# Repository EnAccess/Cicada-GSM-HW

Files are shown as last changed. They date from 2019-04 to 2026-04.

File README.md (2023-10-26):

<p align="center">
  <a href="https://github.com/EnAccess/Cicada-GSM-HW">
    Cicada GSM
  </a>
</p>
<p align="center">
    <em>IoT Communications Module for Energy Access. A quick way to get production ready, bi-directional communications for your IoT embedded device.</em>
</p>
<p align="center">
  
  
  <a href="https://github.com/EnAccess/Cicada-GSM-HW/blob/main/LICENSE" target="_blank">
    
  </a>
</p>

---

# Cicada HW - IoT Communications Module for Energy Access

This repository contains the hardware design of IOT embedded bi-directional communications device. through  2G, 3G, 4G modemsTech.

Checkout the examples in the firmware repository here <https://github.com/EnAccess/Cicada>

## Manufacturing files

If you are only interested in manufacturing the PCBs, you only need files in the /manufacturing/ directory. send them to your contract manufacturer of choice,Some examples of other turnkey PCBA manufacturers are:

| Manufacturers |
|---------------|
| JLCPCB |
| PCBCart |
| Bittele |

The /manufacturing/ directory contains the PCB Gerber/drill files, the BOM, and assembly instructions.

## Source files

If you'd like to take a look at the schematics and PCB layout, first, make sure you have a fresh version of KiCAD. It's a free and open source electronics design tool, and can be downloaded from <http://kicad.org>. Make sure you are not using an old version that some Linux distributions might be still shipping.

### File structure

The schematics and related files live under the /design/ directory:

| Directory | Content |
|---|---|
| /design/doc/datasheets/ | Datasheets for some of the components used. These files are not covered by this project's open source licence |
| /design/pdf | Schematics exported as PDF |
| /design/source/kicad/ | Kicad source files for the CICADA GSM hardwares inculding component lib files |
| /manufacturing/gerber/ |  these are set of files which gives information on different layers used in the project (copper layers, silk screen , court yard and other relevent files) |
| /manufacturing/stackup/ | Text file containing the details of the PCB material and stackup |
| /manufacturing/pick and place/ | Pick and place files describing component locations and orientations for PCB Assembly |
| /manufacturing/nc drill/ | NC Drill files describing type and specification of PCB drill holes (vias, through holes, mounting holes etc) |
| /manufacturing/BOM/ | BOM contains the imformation of all the components used for cicad. directely generated from Kicad using the bom genration script  |

## Standard KiCAD libraries

To make sure we are using the same version of standard KiCAD libraries, we've made a proxy repo that references the KiCAD github repositories, <https://github.com/EnAccess/kicad-libs>. Please clone it along side this repositories, and KiCAD should be able to pick up the schematics symbols / footprints from there:

`/Cicada-HW/` - This repo.

`/kicad-libs/` - Kicad libraries repo.

You might want to remove "global" kicad libraries from your settings to avoid possible version mismatches.

# A quick look at the schematics

The schematics are lagely based on the `SIM7600 Series_Hardware Design_V1.02` and `SIM800C_Hardware_Design_V1.05` documents from Simcom, both found in the documentation folder. Most design festures are shared between the 2G and 4G boards.

## Host interface

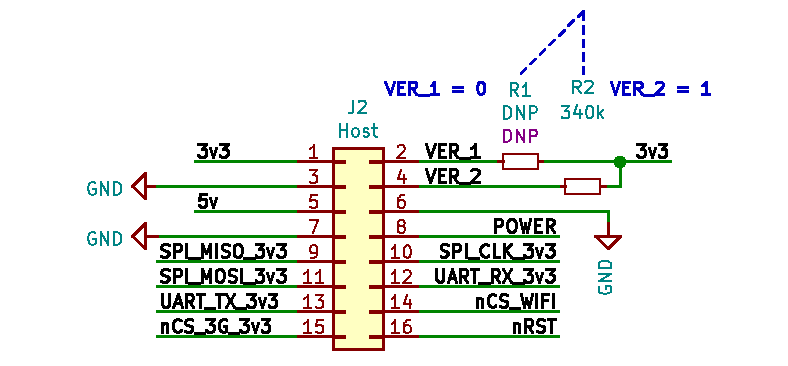
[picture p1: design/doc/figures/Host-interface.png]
Host interface


The host interface provides:

- 5V - power
- 3.3v - logic level VCC reference.
- VER_1 and VER_2 - version pins.
- UART TX and RX.
- SPI - only available on the 4G board as an option. Normally, UART can be used for communication.
- POWER enable pin - drive hogh to enable power.
- RESET pin - drive low to reset, drive at 1.8 - 3.3v during normal operation. Is not implemented on the 2G board, since the SIM800C chip does not have a RESET line.

## Version information

The host interface provides a way for the host to detect the presence of a Cicada board, and distinguish between different boards:

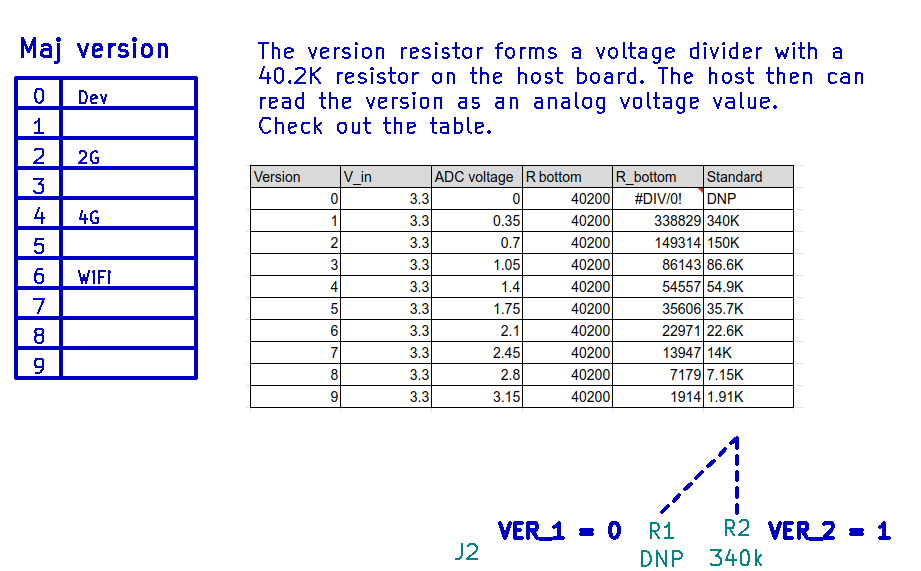
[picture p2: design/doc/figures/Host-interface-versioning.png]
Host interface versioning


## Sim card slot

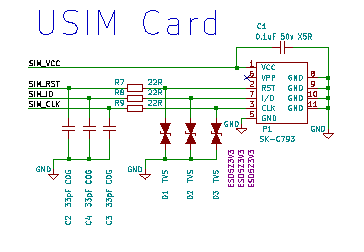
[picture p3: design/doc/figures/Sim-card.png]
Sim card


Same for Cicada 2G and Cicada 4G boards.

## Power

Both Cicada 2G and Cicada 4G use single-chip SMPS to convert 5v down to 4v required by both SIM7600 and SIM800C modules.

Both the modules use M3406-ADJ, which come with a internal over current protection (1.5A) and rated to 800mA operation. but the power supply circuit is design with the bulk output Capacitance which maintaines the voltage and pumps the shorter peak current requirment and the series resister at the power supply input reduce the stress on the hosts 5v regulator.

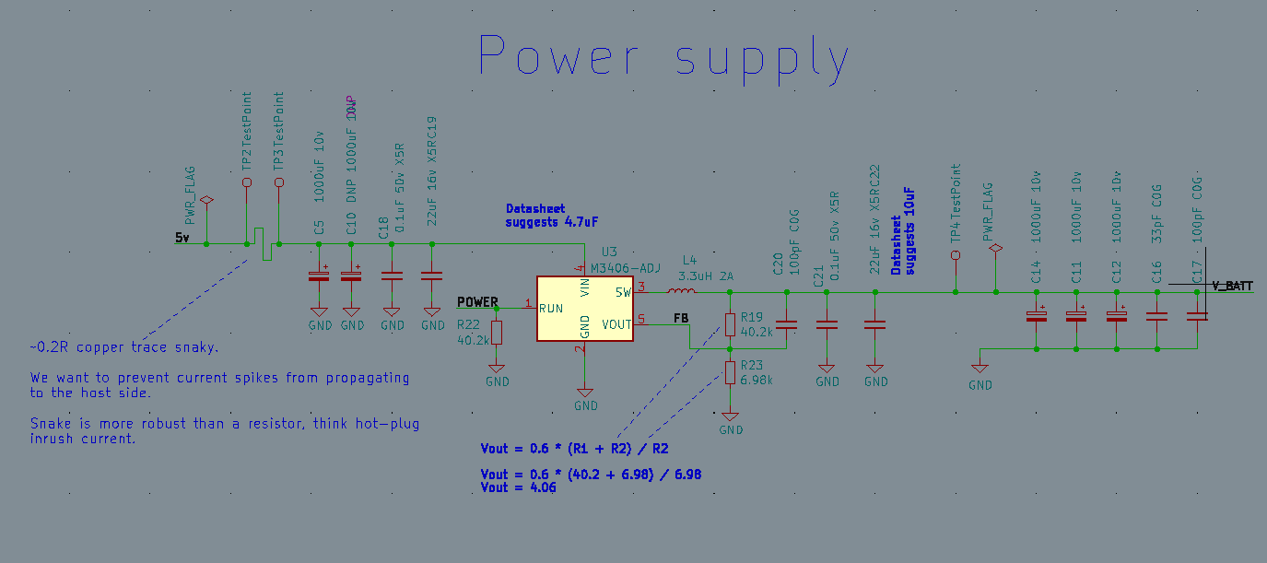
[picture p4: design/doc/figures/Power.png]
Power


## Level shifters

The SIM7600 module (Cicada 4G) operates at 1.8v logic level, while the SIM800C module (Cicada 2G) operates at 2.8v. In both vases, simple discrete level shifters are used to make the logic levels compatible with more common 3.3v.

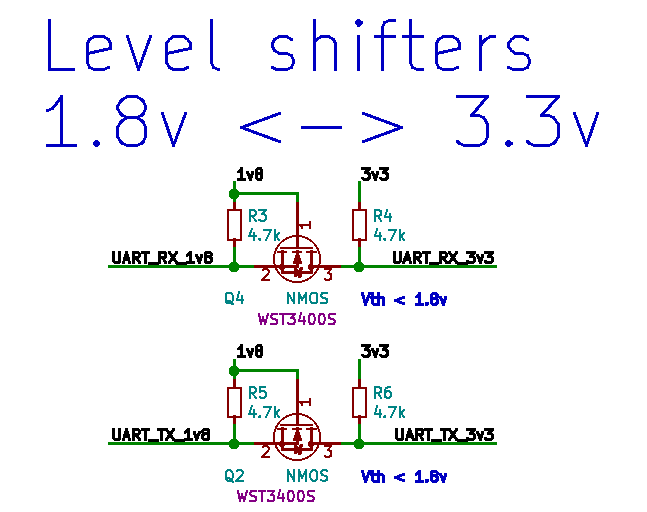
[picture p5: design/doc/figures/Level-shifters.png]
Lvel shifters


## Antennas

Antenna circuitry compied from the simcomm reference documentation:

### Cicada 4G - Main and Auxiliary antennas, plus a GPS antenna

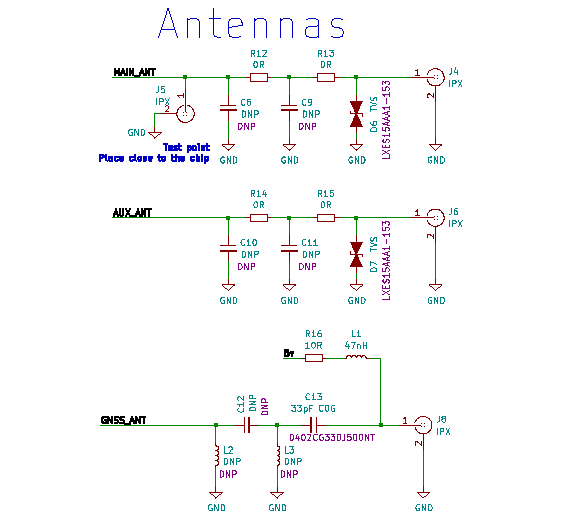
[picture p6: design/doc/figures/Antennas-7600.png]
Antennas 7600


### Cicada 2G - Only the main antenna

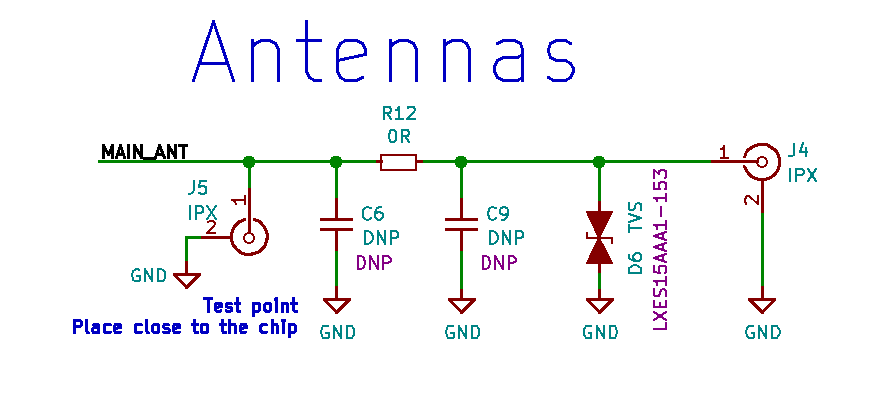
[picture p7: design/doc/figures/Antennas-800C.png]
Antennas 800C


## USB

On both Cicada 2G and Cicada 4G, USB can be used to update the modem firmware.
The USB connector can also provide 5V power to the board during the process.

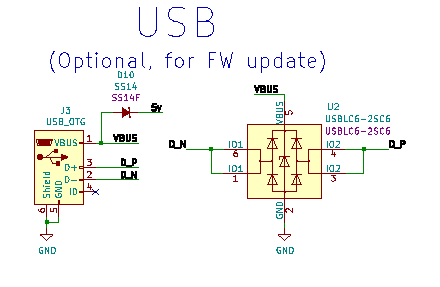
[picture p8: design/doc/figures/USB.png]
USB


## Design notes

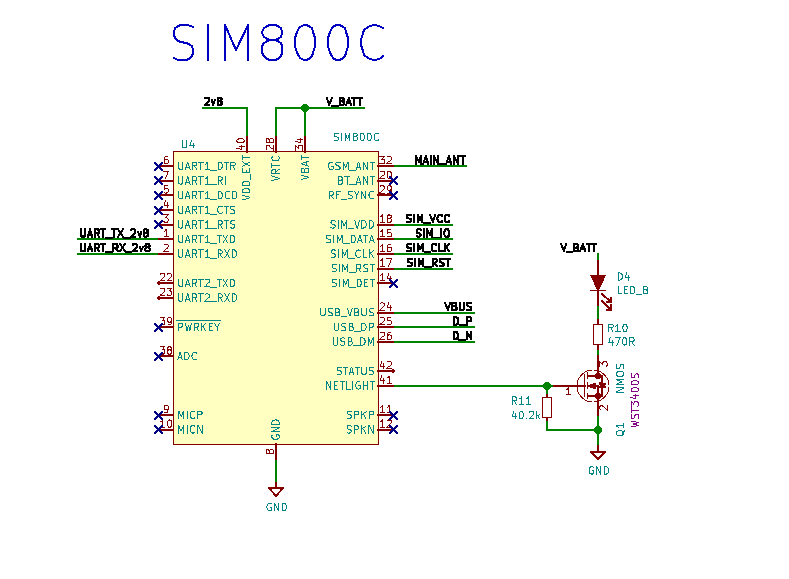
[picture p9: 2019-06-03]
design/doc/notes/Main-800C.png

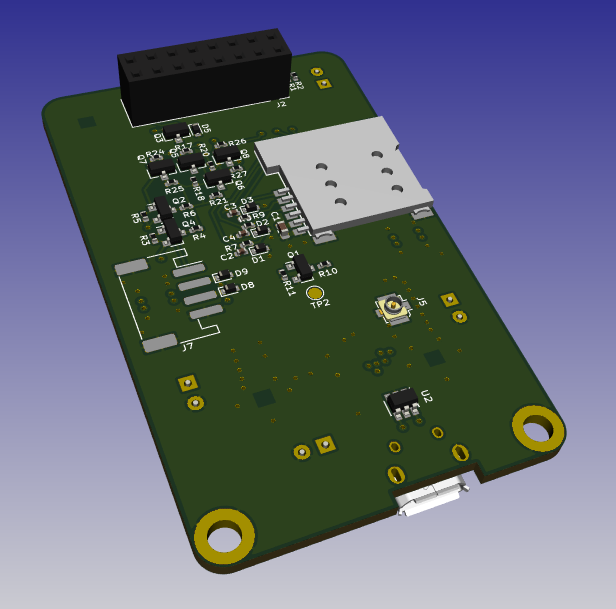
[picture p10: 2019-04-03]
design/renders/cicada-back.png

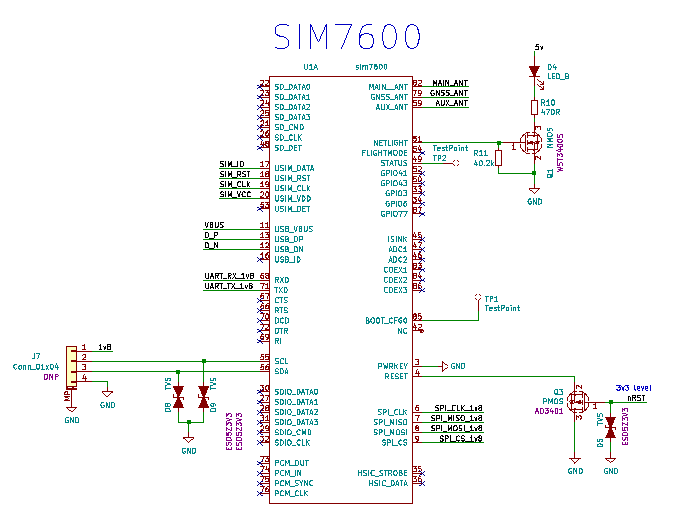
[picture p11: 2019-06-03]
design/doc/notes/Main-7600.png

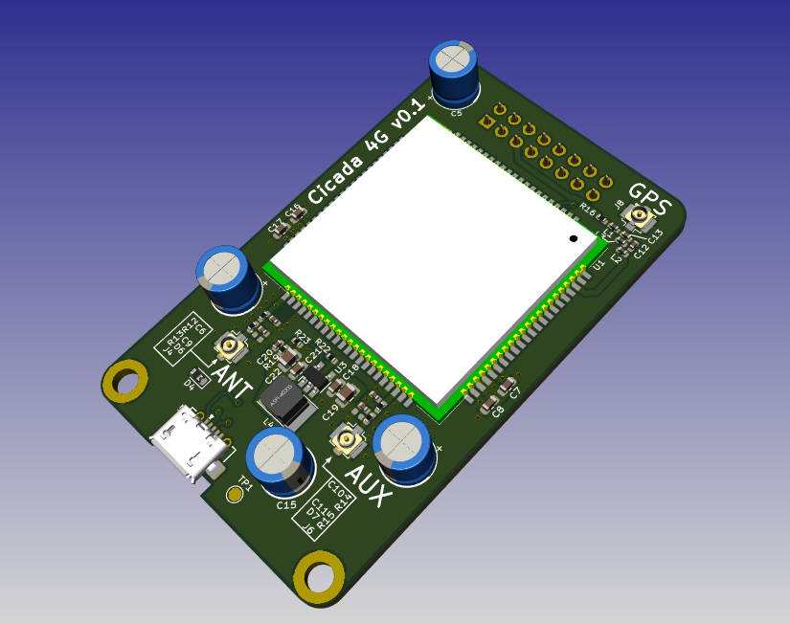
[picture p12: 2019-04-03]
design/renders/cicada-front.png

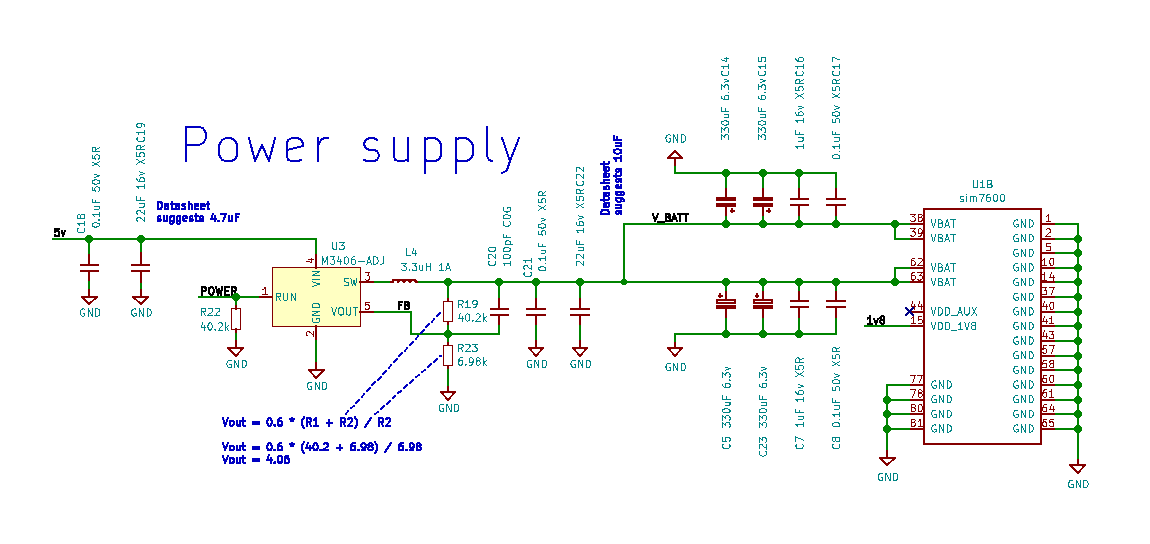
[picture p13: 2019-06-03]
design/doc/notes/Power.png

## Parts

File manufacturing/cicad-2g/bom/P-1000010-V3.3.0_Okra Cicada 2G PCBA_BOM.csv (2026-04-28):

Source: | C:\work\okra\hw\P-1000010_Okra Cicada 2G PCBA\design\source\kicad\P-1000010_Okra Cicada 2G PCBA.kicad_sch
Date: | 2025-07-28T14:56:52+0800
Tool: | Eeschema 9.0.2
Generator: | C:\work\okra\hw\okra_kicad_lib\scripts/OKRA_bom_csv_grouped_by_value_mpn_dnp.py
Component Count: | 57
Collated Components:
Designator | Qty | DNP | Value | Description | Manufacturer | MPN | Footprint | SMT/THT | Alternate Manufacturer 1 | Alternate MPN 1 | Alternate Manufacturer 2 | Alternate MPN 2
C1, C18, C21 | 3 |  | 0.1uF 50v X5R | Unpolarized capacitor, small symbol | Guangdong Fenghua Advanced Tech | 0603B104K500NT | Capacitor_SMD:C_0603_1608Metric | SMT
C2, C3, C4, C16 | 4 |  | 33pF C0G | Unpolarized capacitor, small symbol | Guangdong Fenghua Advanced Tech | 0402CG330J500NT | Capacitor_SMD:C_0402_1005Metric | SMT
C5, C11, C12, C14 | 4 |  | 1000uF 10v | Polarized capacitor, small symbol | Dongguan Chengxing Elec | GR108M010F12RR0VL4FP0 | Capacitor_THT:CP_Radial_D8.0mm_P3.50mm | THT
C6, C7, C8, C9 | 4 | DNP | DNP | Unpolarized capacitor, small symbol |  |  | Capacitor_SMD:C_0402_1005Metric | SMT
C10 | 1 | DNP | DNP 1000uF 10v | Polarized capacitor, small symbol | Dongguan Chengxing Elec | GR108M010F12RR0VL4FP0 | Capacitor_THT:CP_Radial_D8.0mm_P3.50mm | THT
C17, C20 | 2 |  | 100pF C0G | Unpolarized capacitor, small symbol | Guangdong Fenghua Advanced Tech | 0402CG101J500NT | Capacitor_SMD:C_0402_1005Metric | SMT
C19, C22 | 2 |  | 22uF 16v X5R | Unpolarized capacitor, small symbol | Samsung | CL21A226MOQNNNE | Capacitor_SMD:C_0805_2012Metric | SMT
D1, D2, D3 | 3 |  | TVS | Zener diode, filled shape | Tak Cheong | ESD5Z3V3 | Diode_SMD:D_SOD-523 | SMT
D4 | 1 |  | LED_B | Light emitting diode, filled shape | Orient | ORH-B36G | Diode_SMD:D_0603_1608Metric | SMT
D5, D10 | 2 | DNP | SS14 | Diode, small symbol, filled shape | MDD | SS14F | Diode_SMD:D_SMA | SMT
D6 | 1 |  | TVS | Bidirectional transient-voltage-suppression diode, filled shape | Murata Electronics | LXES15AAA1-153 | Diode_SMD:D_0402_1005Metric | SMT
H1, H2 | 2 |  | MountingHole_Pad | Mounting Hole with connection |  |  | MountingHole:MountingHole_3.2mm_M3_ISO14580_Pad | N/A
J2 | 1 |  | Host | Generic 2x10 2.54mm Female | Boom Precision Elec | C30867 | cicada-footprints:PinSocket_2x08_P2.54mm_Vertical_padded | THT
J3 | 1 | DNP | USB_OTG | USB mini/micro connector | Jing Extension of the Electronic | A01SB141B1-067 | cicada-footprints:ZX62D-B-5PA8 | THT
J4 | 1 |  | U.FL | coaxial connector (BNC, SMA, SMB, SMC, Cinch/RCA, ...) | Hirose | U.FL-R-SMT-1(80) | cicada-footprints:U.FL_Molex_MCRF_73412-0110_Vertical | SMT
J5 | 1 | DNP | DNP U.FL | coaxial connector (BNC, SMA, SMB, SMC, Cinch/RCA, ...) | Hirose | U.FL-R-SMT-1(80) | cicada-footprints:U.FL_Molex_MCRF_73412-0110_Vertical | SMT
L4 | 1 |  | 3.3uH 2A | Inductor, small symbol | TAITEC | FPI0403F-3R3M | cicada-footprints:L_4030_Handsoldering | SMT | YJYCOIN | CD43YP0403-3R3M
LOGO1 | 1 |  | SYM_Hot_Small | Hot surface warning symbol, small |  |  | cicada-footprints:okra_logo_copper_2 | N/A
P1 | 1 |  | SK-C793 |  | Shenzhen Shengkai Electronics | SK-C793 | cicada-footprints:SK-C793 | SMT
PCB1 | 1 | DNP | P-1000010 Bare PCB |  |  |  |  | N/A
Q1 | 1 |  | 2N7002 | 0.115A Id, 60V Vds, N-Channel MOSFET, SOT-23 | Guangdong Hottech | 2N7002 | Package_TO_SOT_SMD:SOT-23 | SMT
R1 | 1 |  | 150k | Resistor, small symbol | YAGEO | RC0402JR-07150KL | Resistor_SMD:R_0402_1005Metric | SMT
R2 | 1 |  | 86.6k | Resistor, small symbol | YAGEO | RC0402FR-0786K6L | Resistor_SMD:R_0402_1005Metric | SMT
R3, R4 | 2 |  | 330R | Resistor, small symbol | YAGEO | RC0402FR-07330RL | Resistor_SMD:R_0402_1005Metric | SMT
R7, R8, R9 | 3 |  | 22R | Resistor, small symbol | YAGEO | RC0402FR-0722RL | Resistor_SMD:R_0402_1005Metric | SMT
R10 | 1 |  | 1K | Resistor, small symbol | YAGEO | RC0402JR-071KL | Resistor_SMD:R_0402_1005Metric | SMT
R12, R13 | 2 |  | 0R | Resistor, small symbol | YAGEO | RC0402FR-070RL | Resistor_SMD:R_0402_1005Metric | SMT
R14 | 1 | DNP | 6.98k | Resistor, small symbol | YAGEO | RC0402FR-076K98L | Resistor_SMD:R_0402_1005Metric | SMT
R19, R22 | 2 |  | 40.2k | Resistor, small symbol | YAGEO | RC0402FR-0740K2L | Resistor_SMD:R_0402_1005Metric | SMT
R23 | 1 |  | 6.98k | Resistor, small symbol | YAGEO | RC0402FR-076K98L | Resistor_SMD:R_0402_1005Metric | SMT
U1, U5 | 2 |  | 74LVC1G17 | Single Schmitt Buffer Gate, Low-Voltage CMOS | NXP Semicon | 74LVC1G17GW | Package_TO_SOT_SMD:SOT-353_SC-70-5 | SMT
U2 | 1 | DNP | USBLC6-2SC6 | Bidirectional ESD Protection Diode, SOT-23-6 | Yenji Elec | USBLC6-2SC6 | Package_TO_SOT_SMD:SOT-23-6 | SMT
U3 | 1 |  | MT3406 | 600mA Synchronous Step-Down Regulator, 1.5MHz, Adjustable Output Voltage, Burst Mode, ThinSOT-23 | XI'AN Aerosemi Tech | MT3406 | Package_TO_SOT_SMD:TSOT-23-5 | SMT
U4 | 1 |  | SIM800C (ordinary version) | GSM Quad-Band Communication Module, GPRS, Audio Engine, AT Command Set, Bluetooth is Optional | Simcom | SIM800C | RF_GSM:SIMCom_SIM800C | SMT

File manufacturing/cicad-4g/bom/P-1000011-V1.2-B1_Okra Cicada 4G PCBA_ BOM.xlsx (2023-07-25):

Reference | Qty | DNP | Requirement | Part | Manufacturer | Part number | Source | Source number | Price | Total Price
C1 C17 C18 C21 C8 | 5 |  | 0.1uF 50v X5R 0603 | P5: 0.1uF 50v 0603 X7R | SAMSUNG | CL10B104KB8NNNC | LCSC | C1591 | 0.0028 | 0.014000
C13 C2 C3 C4 | 4 |  | 33pF C0G 0402 | P18: 33pF 50v 0402 COG | SAMSUNG | CL05C330JB5NNNC | LCSC | C70465 | 0.0021 | 0.008400
C14 C15 C23 C24 C25 C5 | 6 |  | 1000uF 10v D=8mm p=3.5mm | P147: 1000uF 10V 8x12mm p=3.5mm 3000H@105C | Dongguan Ocean Electronic Technology | GR108M010F12RR0VL4FP0 | LCSC | C3299 | 0.0171 | 0.102600
C16 C7 | 2 |  | 1uF 16v X5R 0603 | P3: 1uF 50v 0603 X5R | SAMSUNG | CL10A105KB8NNNC | LCSC | C15849 | 0.0066 | 0.013200
C19 C22 | 2 |  | 22uF 16v X5R 0805 | P159: 22uF 16V 0805 X5R | SAMSUNG | CL21A226MOQNNNE | LCSC | C98190 | 0.0294 | 0.058800
C20 | 1 |  | 100pF C0G 0402 | P20: 100pF 50v 0402 COG | SAMSUNG | CL05C101JB5NNNC | LCSC | C26409 | 0.0025 | 0.002500
D1 D2 D3 D5 D8 D9 | 6 |  | TVS | P152: ESD diode 3.3v SOD-523 | Tak Cheong | ESD5Z3V3 | LCSC | C129213 | 0.0103 | 0.061800
D4 | 1 |  | LED_B | P37: LED 0603 Blue | BrtLed | BL-HB336G-TRB | LCSC | C138541 | 0.0092 | 0.009200
D6 D7 | 2 |  | TVS | P142: ESD diode 0402 4V | Murata | LXES15AAA1-153 | LCSC | C86141 | 0.0191 | 0.038200
D10 D11 | 2 |  | SS14 SMA | P43: Schottky Diode SMA (DO-214AC) 40V 1A | MDD | SS14 | LCSC | C2480 | 0.0069 | 0.013800
J2 | 1 |  | Host Pin socket 2x10 | P218: 2x10 2.54mm Straight double row female socket | Boom Precision Elec |  | LCSC | C30867 | 0.0725 | 0.072457
J3 | 1 |  | USB_OTG | P158: USB Micro SMD Jing | Jing Extension | C10418 | LCSC | C10418 | 0.0339 | 0.033900
J4 J5 J6 J8 | 4 |  | IPX | P114: U.FL Receptacle Male Pin SMD RF | Hirose | U.FL-R-SMT-1(80) | LCSC | C88374 | 0.0444 | 0.177600
L1 | 1 |  | 47nH 0402 |  |  |  |  |  |  | 0.000000
L4 | 1 |  | 3.3uH 2A 4030 | P154: 3.3uH 2A 4.5x4x3.2mm 20% | TAITEC | FPI0403F-3R3M | LCSC | C304284 | 0.0108 | 0.010800
P1 | 1 |  | SK-C793 | P140: Micro Sim card holder SK-C793 | Shenzhen Shengkai Electronics | SK-C793 | Taobao | https://item.taobao.com/item.htm?id=563346633219 |  | 0.000000
Q1 Q2 Q4 Q5 Q6 Q7 Q8 | 7 |  | NMOS SOT-23 AO3400 analog | P107: Power NMOS 30V SOT-23-3 35mR | Guangdong Hottech | AO3400 | LCSC | C181090 | 0.0236 | 0.165200
Q3 | 1 |  | PMOS SOT-23 AO3401 analog | P105: Power PMOS 30V SOT-23-3 65mR | Guangdong Hottech | AO3401 | LCSC | C181091 | 0.0203 | 0.020300
R1 | 1 |  | 54.9k 0402 |  |  |  |  |  |  | 0.000000
R2 | 1 |  | 340k 0402 |  |  |  |  |  |  | 0.000000
R7 R8 R9 | 3 |  | 22R 0402 |  |  |  |  |  |  | 0.000000
R10 | 1 |  | 470R 0402 |  |  |  |  |  |  | 0.000000
R11 R19 R22 | 3 |  | 40.2k 0402 |  |  |  |  |  |  | 0.000000
R12 R13 R14 R15 | 4 |  | 0R 0402 |  |  |  |  |  |  | 0.000000
R16 | 1 |  | 10R 0402 |  |  |  |  |  |  | 0.000000
R17 R18 R20 R21 R24 R25 R26 R27 R3 R4 R5 R6 | 12 |  | 4.7k 0402 |  |  |  |  |  |  | 0.000000
R23 | 1 |  | 6.98k 0402 |  |  |  |  |  |  | 0.000000
U1 | 1 |  | sim7600 | P219: SIM7600CE-L1C | Simcom | SIM7600CE-L1C | Taobao | https://item.taobao.com/item.htm?id=549911412988 | 15.0000 | 15.000000
U2 | 1 |  | USBLC6-2SC6 SOT23-6 | P150: ESD diode SOT-23-6 5v | STMicroelectronics | USBLC6-2SC6 | LCSC | C7519 | 0.0504 | 0.050400
U3 | 1 |  | M3406-ADJ TSOT-23-5 | P55: M3406-ADJ SOT-23-5 Step-Down 6V Adjustable DC-DC | XI'AN Aerosemi Tech | M3406-ADJ | LCSC | C83224 | 0.0272 | 0.027200
C10 C11 C12 C6 C9 | 5 | DNP | DNP 0402 |  |  |  |  |  |  | 0.000000
J7 | 1 | DNP | Conn_01x04 Male pin header 4p 2.54mm |  |  |  |  |  |  | 0.000000
L2 L3 | 2 | DNP | DNP 0402 |  |  |  |  |  |  | 0.000000
 |  |  |  |  |  |  |  |  |  | 0.000000

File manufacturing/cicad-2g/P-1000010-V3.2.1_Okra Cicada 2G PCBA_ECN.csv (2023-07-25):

Bom_Level | Parent Part | Part Number | Designator | Change Description | Old Version Number | New Version Number | Release Date | Change Type (modify,remove,add) | Design/Document Change | Change Over Process (Running, Immediate) | Old CM Part Number | New CM Part Number | Old MPN | New MPN | Old Manufacturer | New Manufacturer | Reason for Change
1 |  | P-1000010_Okra Cicada 2G PCBA | BOM | generated new bom file | 3.2.0 | 3.2.1 | 2022-04-29 | Modify | Document | immediate | N/A | N/A | N/A | N/A | N/A | N/A | bom file not updated in previous release
1 |  | P-1000010_Okra Cicada 2G PCBA | L4 | Add alternate part | 3.1.0 | 3.2.0 | 2022-04-22 | Alternate | Design | Running | 1102-000133-00 |  | FPI0403F-3R3M | CD43YP0403-3R3M | TAITEC | YJYCOIN | Supply issues resulted in the alternate being used for Run 4 (V10.1)
1 |  | P-1000010_Okra Cicada 2G PCBA | J4 | - Replace J4 with Hirose U.FL-R-SMT-1(80) (was previously Murata Electronics MM4829-2702RA4 which is incorrect style of coax connector) - Added test instructions | 3.0.1 | 3.1.0 | 12-08-2020 | Modify | Design | Immediate | N/A | N/A | N/A | N/A | Okra | Okra | N/A
1 |  | P-1000010_Okra Cicada 2G PCBA |  | - Updated NC Drill and Pick N Place files (these were not regenerated for last release) - Removed Assembly files as these are not generated for the other PCBs | 3.0.0 | 3.0.1 |  | Modify | Documentation | Immediate | N/A | N/A | N/A | N/A | Okra | Okra | N/A

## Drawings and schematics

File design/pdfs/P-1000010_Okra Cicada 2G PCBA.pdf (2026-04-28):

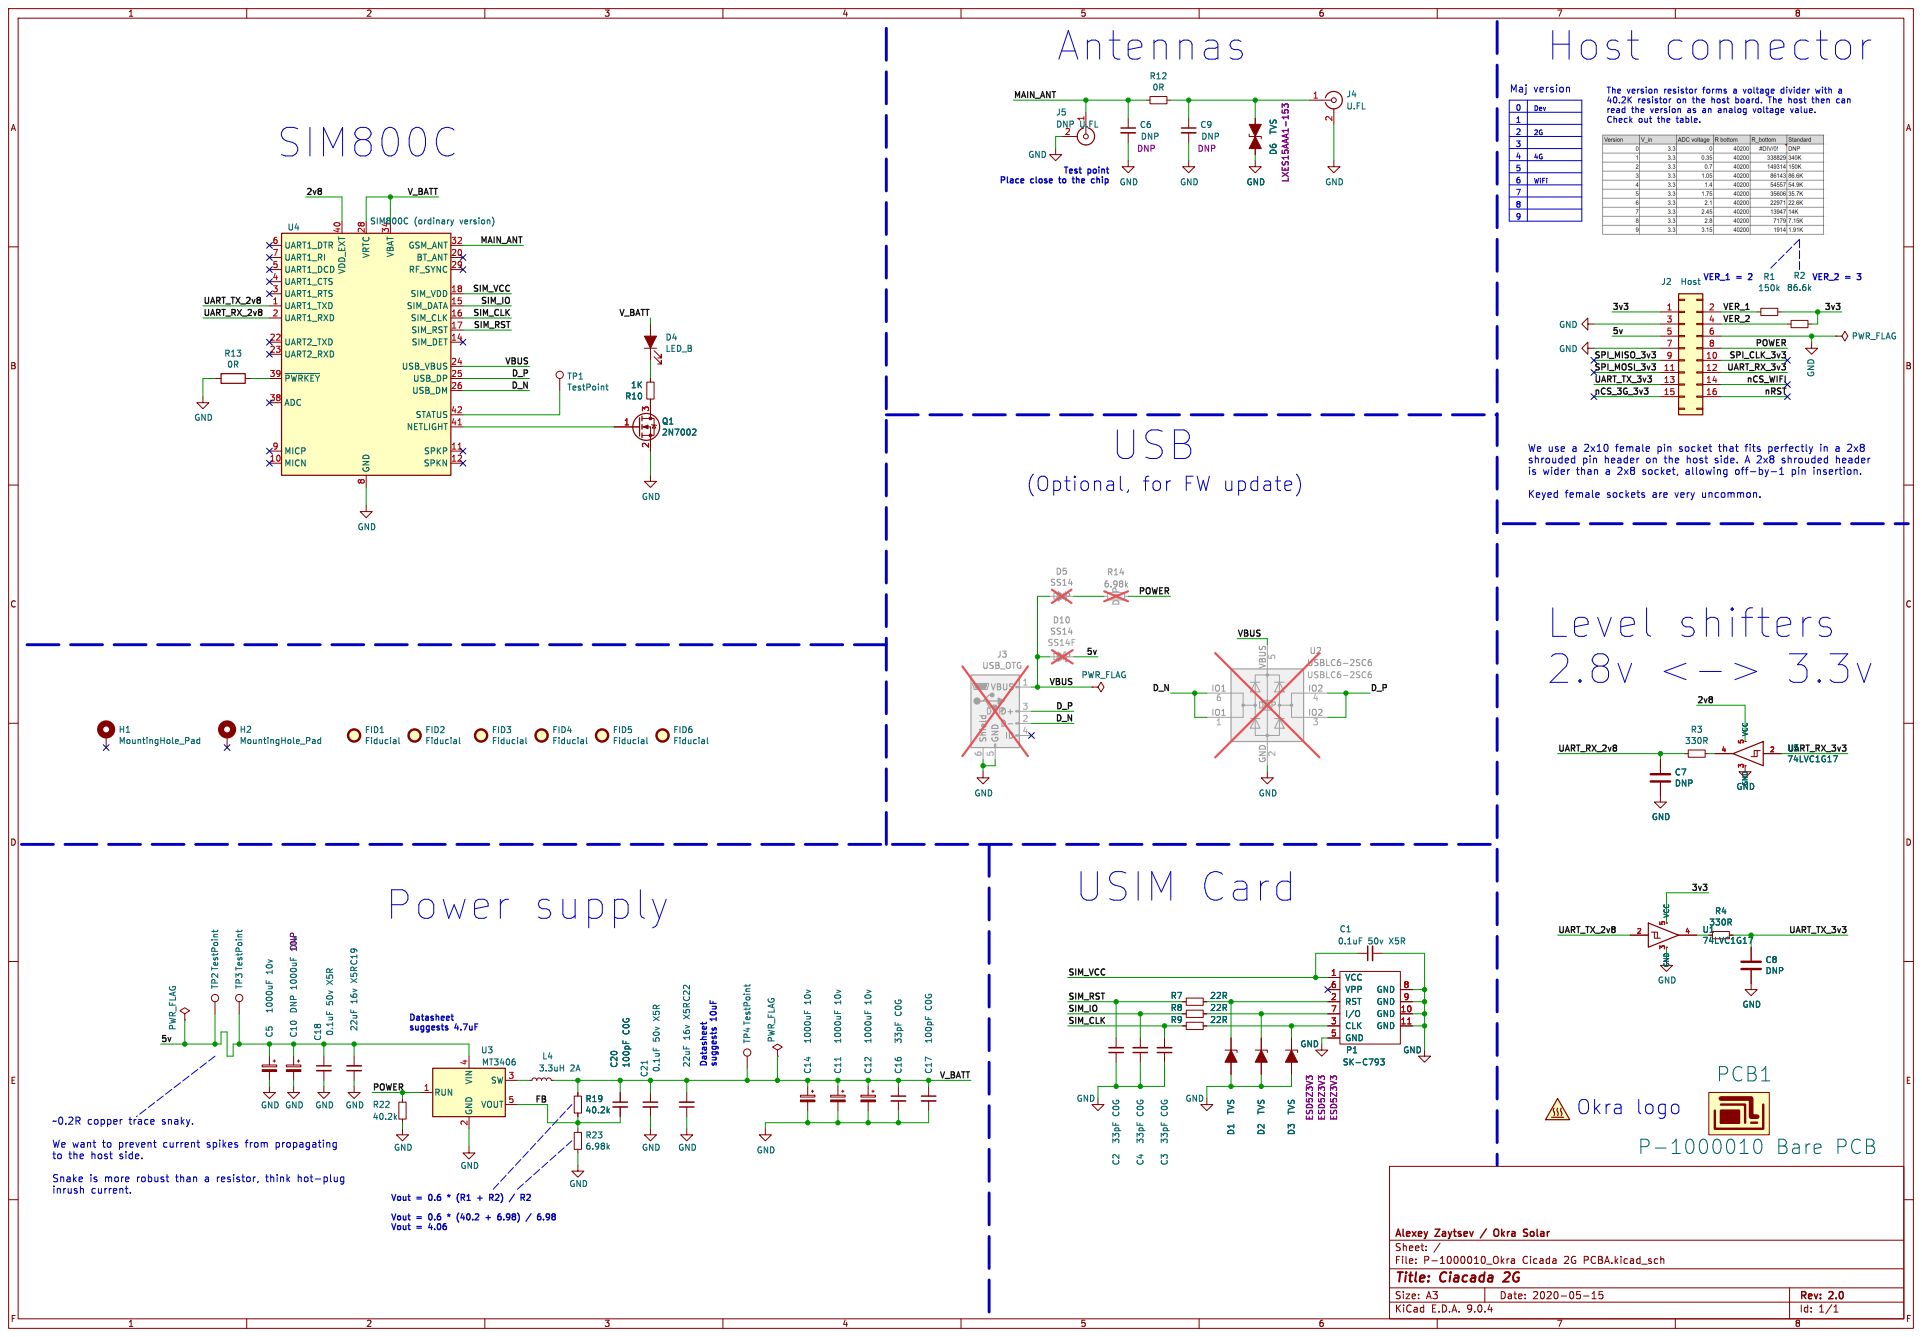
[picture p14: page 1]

read the version as an analog voltage value. Check out the table. 8

GND
Test point Place close to the chip

8 VBAT 34 GSM_ANT 32 BT_ANT 20 RF_SYNC 29 SIM_VDD 18 SIM_DATA 15 SIM_CLK 16 SIM_RST 17 SIM_DET 14 USB_VBUS 24 USB_DP 25 USB_DM 26 STATUS 42 NETLIGHT 41 SPKP 11 SPKN 12 U4 SIM800C (ordinary version) 1

shrouded pin header on the host side. A 2x8 shrouded header

2 SW 3 VOUT 5 U3MT3406 PWR_FLAG TP4 TestPoint C22 22uF 16v X5R GND Shield

~0.2R copper trace snaky. We want to prevent current spikes from propagating

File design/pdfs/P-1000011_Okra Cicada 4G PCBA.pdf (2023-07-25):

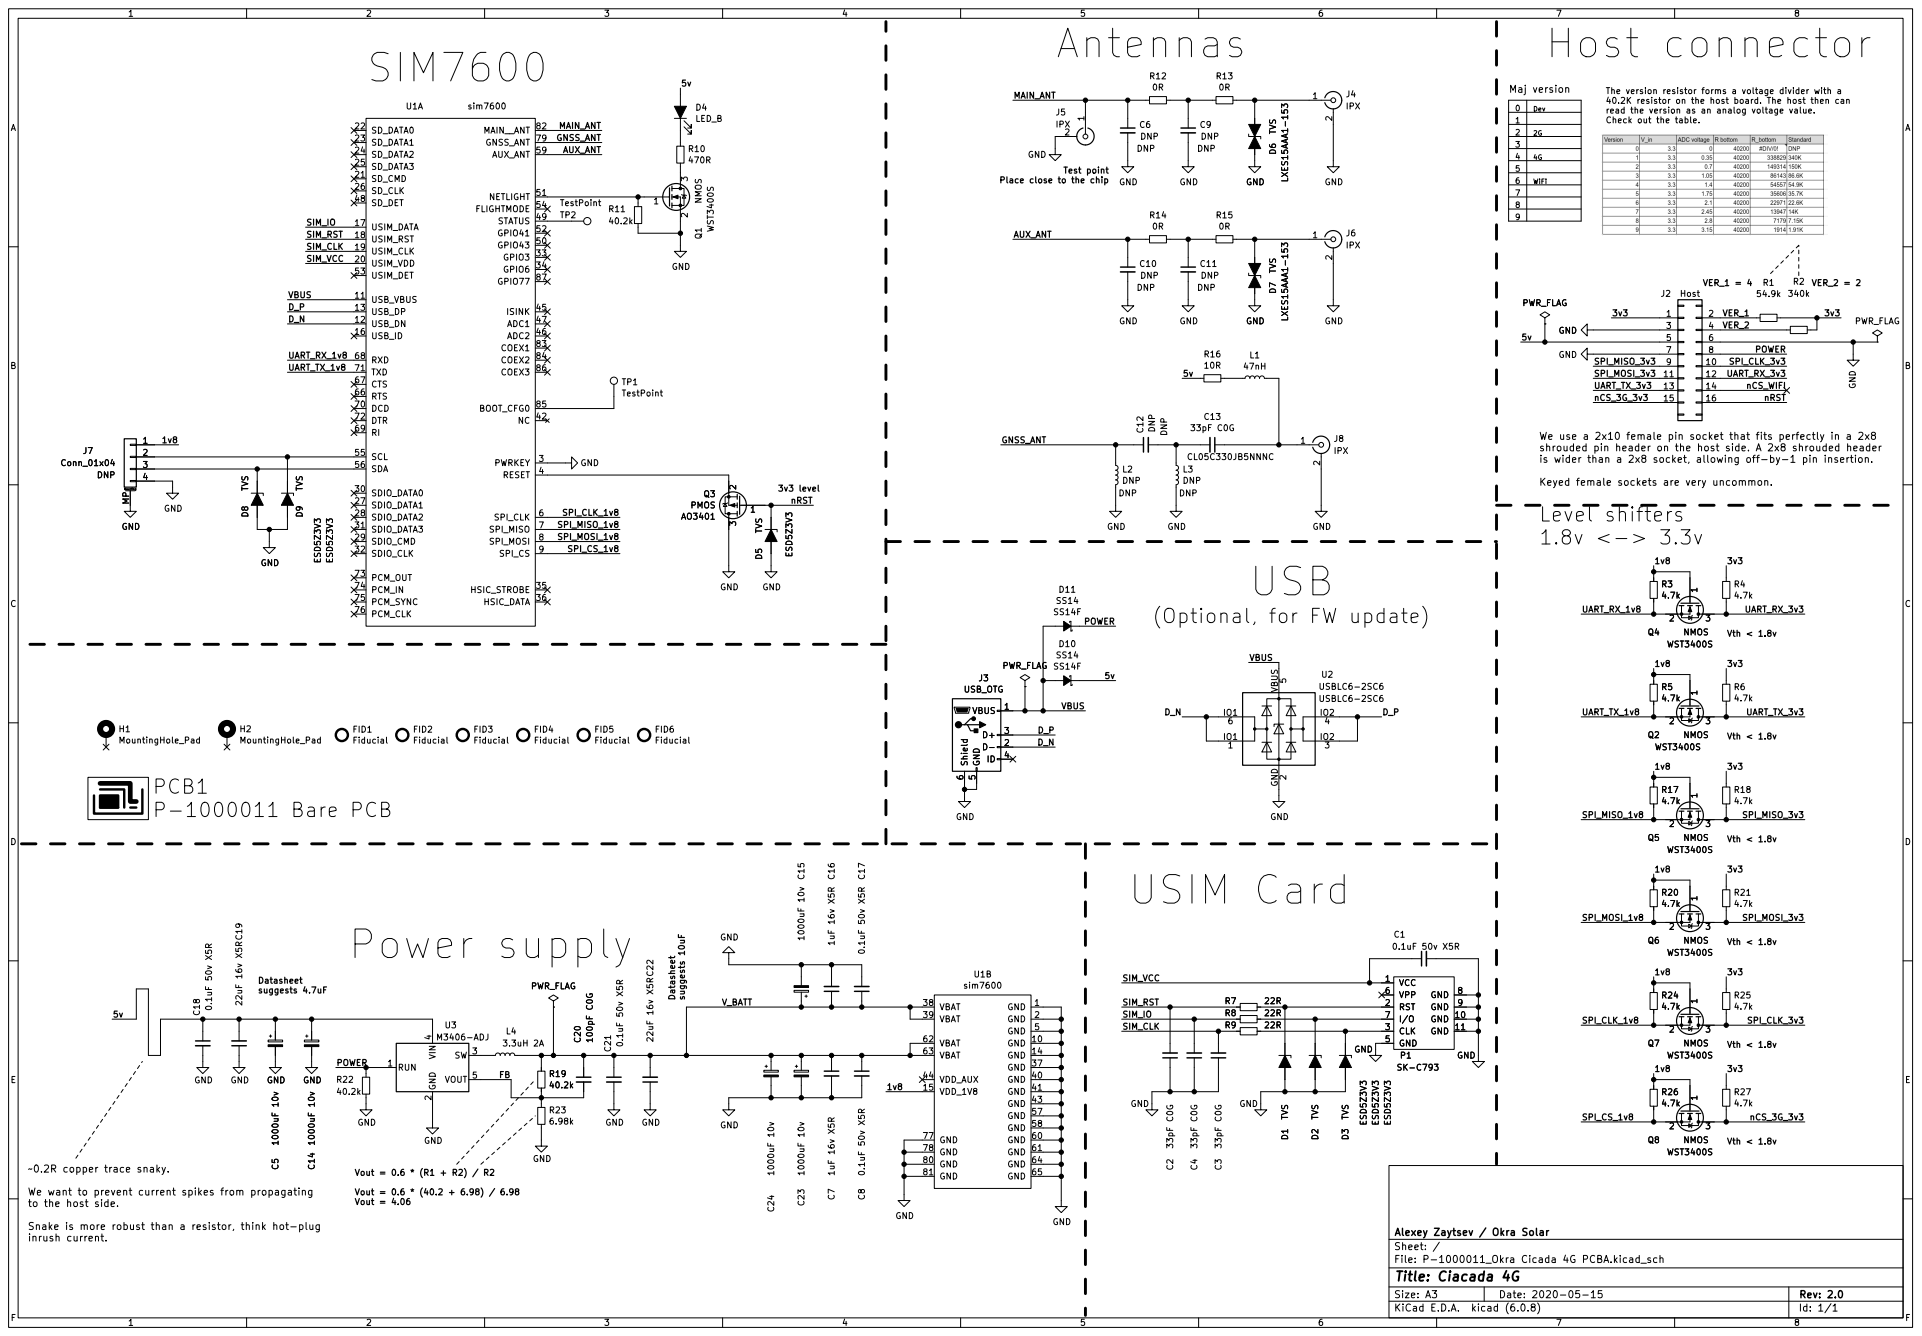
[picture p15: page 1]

read the version as an analog voltage value. Check out the table. Host connector
2GWiFi 4GLevel shifters

VER_1 = 4 The version resistor forms a voltage divider with a
40.2K resistor on the host board. The host then can

GND D7 TVS LXES15AAA1-153 GND D6 TVS LXES15AAA1-153 GND

Place close to the chip

shrouded pin header on the host side. A 2x8 shrouded header
is wider than a 2x8 socket, allowing off-by-1 pin insertion.

2 3 D5 TVS ESD5Z3V3 PWR_FLAG D9 TVS ESD5Z3V3 D8 TVS ESD5Z3V3 GND

Keyed female sockets are very uncommon.

SPI_MOSI_1v8 (Optional, for FW update)

4 VOUT 5 U3 M3406-ADJ GND GND

Vth < 1.8v ~0.2R copper trace snaky.

We want to prevent current spikes from propagating
to the host side. Snake is more robust than a resistor, think hot-plug

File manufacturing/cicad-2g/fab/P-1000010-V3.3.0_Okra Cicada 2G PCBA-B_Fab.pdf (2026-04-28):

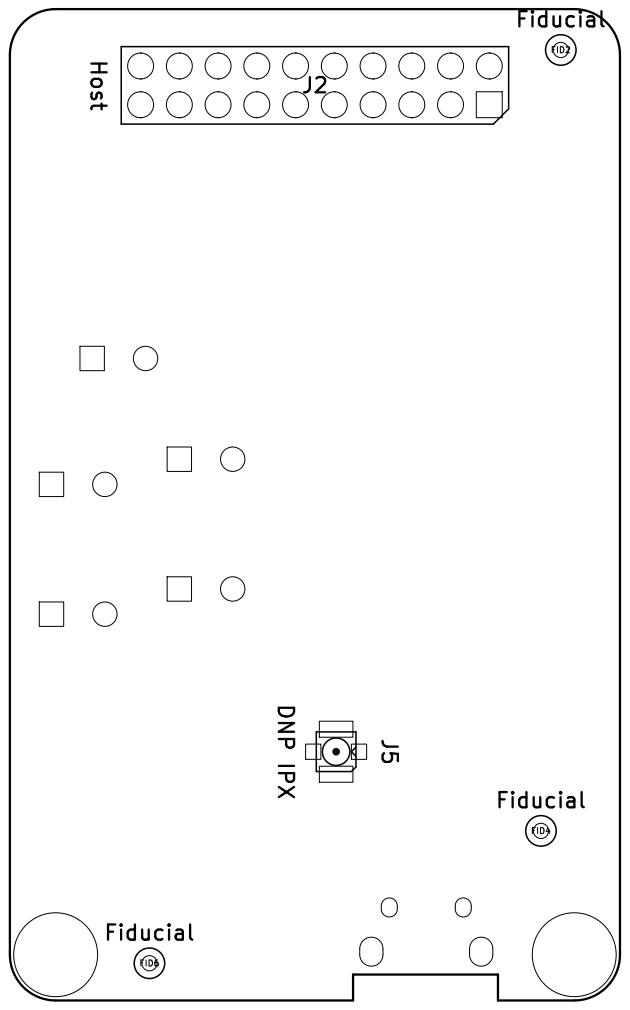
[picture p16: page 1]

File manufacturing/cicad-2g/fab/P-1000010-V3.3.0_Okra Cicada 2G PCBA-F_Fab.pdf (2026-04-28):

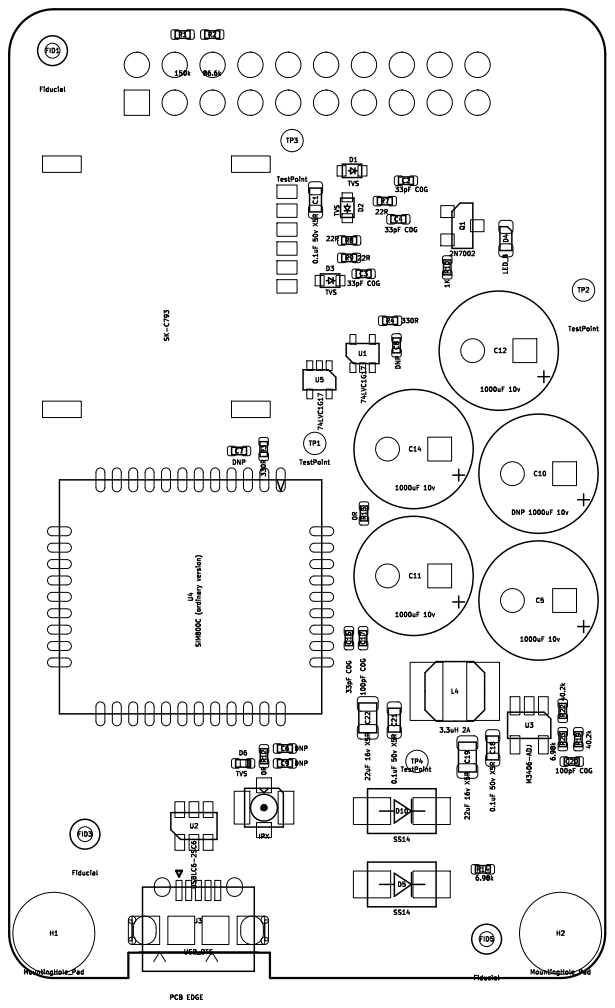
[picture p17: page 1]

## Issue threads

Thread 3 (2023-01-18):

Support the use of eSIM rather than physical SIM

dmohns, 2023-01-18:
Physical SIM cards and specifically the SIM card holders can be prone to errors and failures for devices in the field. It would be great to explore to option of using eSIM instead.

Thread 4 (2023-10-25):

Upgrade KiCad files to version 7

dmohns, 2023-10-25:
To avoid conflicts and warnings when the PCB's files get opened with newer version.

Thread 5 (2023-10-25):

Clarify the latest `REVISION` of the Cicada 2G module

dmohns, 2023-10-25:
All the PCB's seem to suggest the latest version is called 2.0. And in fact, that's what the assembled device has printed on. But all the GERBER files are called v1.2

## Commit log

2019-03-29 Initial commit - preliminary schematics
    [okra-cicada.kicad_pcb, okra-cicada.sch]
2019-04-03 Finish up initial schematics, add layout
    - Add preliminary PCB layout
    - Add USB connector library
    - Add SIM card slot library
    [cicada.kicad_pcb, cicada.sch, okra-cicada.kicad_pcb]
2019-04-03 Add more libraries and documentation
    - Add schematics PDF
    - Add PCB 3D renderings
    - Add Abracon inductor library
    - Add antenna connector library
    - Update USB connector library
    [cicada.kicad_pcb, cicada.sch]
2019-04-03 Re-arrange schematics
    Re-arrange the schematics drawing for better visibility.
    [cicada.sch]
2019-04-03 Improve PCB layout
    Various fixes and improvements for layout.
    [cicada.kicad_pcb]
2019-04-03 Finish up layout
    This layout is ready for manufacturing.
    [cicada.kicad_pcb, cicada.sch]
2019-04-04 Add a diode to be able to power from USB. PCB cleanups.
    [cicada.kicad_pcb, cicada.sch]
2019-04-15 Clean up and prepare files for the first prototype run
    [cicada-4g-v1-BOM-2019-04-13.xlsx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]
2019-04-15 Rename cicada -> cicada 4g
    [cicada-4g.kicad_pcb, cicada-4g.sch]
2019-05-20 Add Cicada 2G
    [cicada-2g-B_Cu.gbl, cicada-2g-B_Mask.gbs, cicada-2g-B_Paste.gbp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]
2019-06-03 Cicada 4G v1.1 - don't swap RX-TX
    [cicada-4g.kicad_pcb, cicada-4g.sch]
2019-06-03 Cicada 2G v2.1 - don't swap RX-TX
    [cicada-2g.kicad_pcb, cicada-2g.sch]
2019-06-03 Cicada 2G v1.1 manufacturing files
    [cicada-2g-B_Cu.gbl, cicada-2g-B_Mask.gbs, cicada-2g-B_Paste.gbp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]
2019-06-03 Remove OKRA logo from PCB
    [cicada-2g.kicad_pcb]
2019-06-03 Cicada 4G v1.1 manufacturing files
    [cicada-4g-B_Cu.gbl, cicada-4g-B_Mask.gbs, cicada-4g-B_Paste.gbp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]
2019-06-03 Add schematics PDFs for Cicada 2G/4G
2019-09-30 Grounded PWRKEY
    [cicada-2g.sch]
2019-09-30 Added POWER pull-up when powered from USB
    [cicada-2g.sch]
2019-09-30 Replaced FET level shifters with 74LVC1G17GW
    [cicada-2g.sch]
2019-10-02 Added okra logo footprint
2019-10-03 Fixed version and changed LED driver
    [cicada-2g.sch]
2019-10-04 Updated connector and capacitors
    [cicada-2g.sch]
2019-10-04 Updated PCB
    [cicada-2g.kicad_pcb, cicada-2g.sch]
2019-10-07 Generated manufacturing package
    [cicada-2g-B_Cu.gbl, cicada-2g-B_Mask.gbs, cicada-2g-B_Paste.gbp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]
2019-12-08 Clean up the component libraries
    [cicada-2g.kicad_pcb, cicada-2g.sch]
2019-12-08 Update component library references in Cicada 4G
    [cicada-4g.kicad_pcb, cicada-4g.sch]
2019-12-08 Update the library directory structure to match other Okra projects
    [cicada-2g.kicad_pcb, cicada-2g.sch, cicada-4g.kicad_pcb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]
2019-12-08 Add the kicad bom2csv BOM script to the component library
2021-11-09 Update README.md
    https://forum.kicad.info/t/warning-avoid-all-links-to-kicad-pcb-org-use-kicad-org/31521
2023-07-25 Commit notes -both 2g and 4g cicada design revision has been updated to latest production and tested revision. both design now use kiCAD-6 -some of the missing Footprints added to lib folder -readme 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
    [P-1000010-V3.2.1_Okra Cicada 2G PCBA_BOM.csv, P-1000010-V3.2.1_Okra Cicada 2G PCBA_ECN.csv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]
2026-04-28 update to revision 3.3.0 shared by OKRA (#13)
    [P-1000010-V3.2.1_Okra Cicada 2G PCBA_BOM.csv, P-1000010-V3.3.0_Okra Cicada 2G PCBA_BOM.csv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]
